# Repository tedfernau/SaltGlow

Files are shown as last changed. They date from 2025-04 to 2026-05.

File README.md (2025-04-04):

# SaltGlow

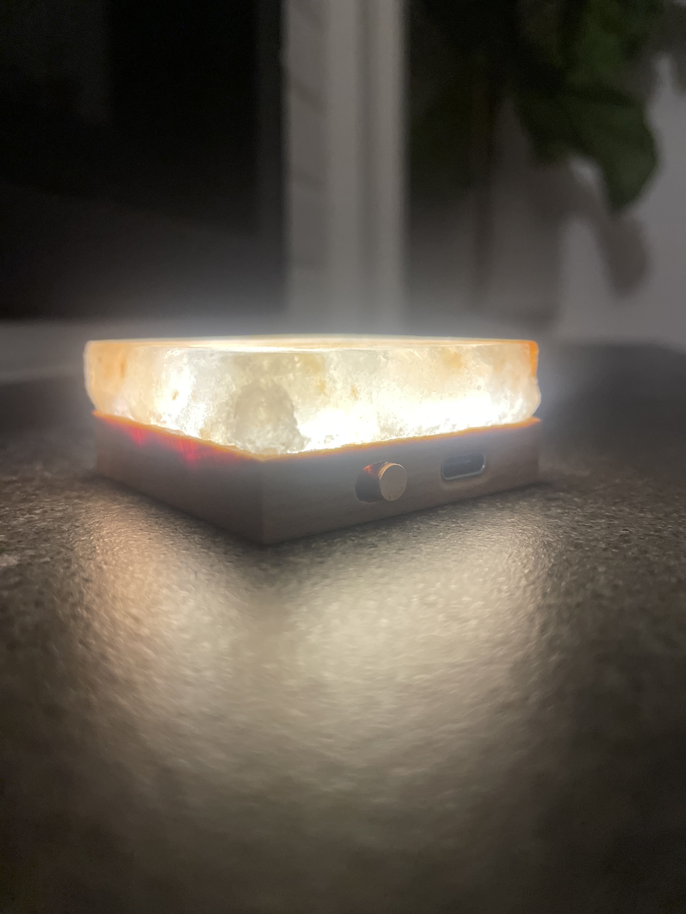
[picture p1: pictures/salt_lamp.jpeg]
SaltGlow


A portable saltlamp for camping, reading, or just setting the mood. 

Simple materials for modern living: Salt, Copper, Wood. 

Features: \
-USBC rechargable in less than 2 hours (100 minutes) (dumb charger only)\
-11 hour battery life - Max Brightness\
-about 5.5 days battery life - Low Brightness\
-3 Brightness Settings\
-Simple Materials\
-Each Lamp is Unique\
-Hand Assembled and Salt Selected\
-Designed in USA\
-Small Batch\

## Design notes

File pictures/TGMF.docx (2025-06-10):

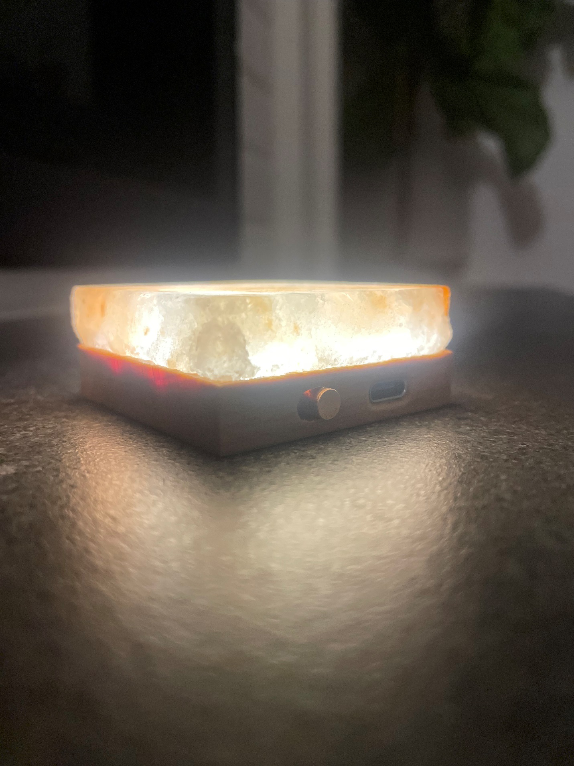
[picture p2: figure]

TGMF

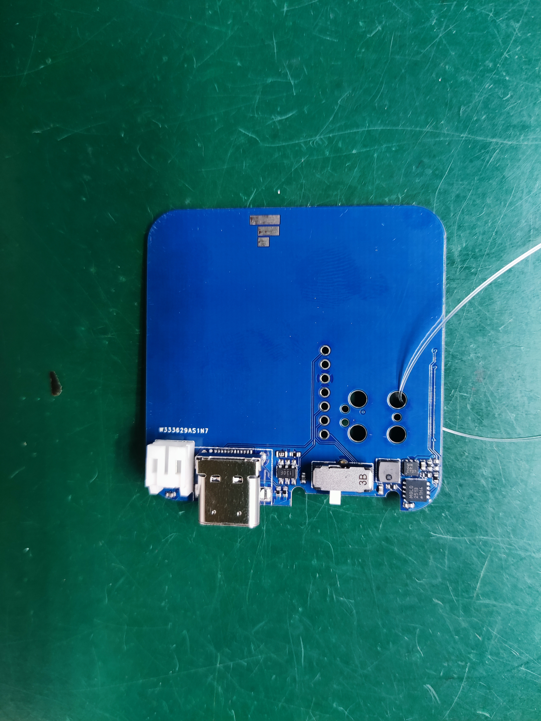
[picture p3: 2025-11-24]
pictures/T-1N8W333629A1.jpg

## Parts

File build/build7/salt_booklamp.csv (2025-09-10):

# | Qty | Reference | Manufacturer Part Number | Value
1 | 1 | BATT1 | S2B-PH-K-S | S2B-PH-K-S
2 | 5 | C1,C2,C3,C4,C5 | EMK105BJ105KV-F | 1uF
3 | 1 | J1 | USB-C31-S-RA-CS1E-BK-T/R | USB-C31-S-RA-CS1E-BK-T/R
4 | 1 | L1 | VLS3012CX-220M-1 | 22uH
5 | 3 | LED1,LED2,LED3 | SMS1105UWDW | SMS1105UWDW
6 | 4 | R1,R3,R4,R5 | RC0402JR-0710KL | 10k0
7 | 1 | R2 | CRCW04026R80FKED | 6r8
8 | 1 | R6 | CR0603-FX-1201ELF | 1k2
9 | 2 | R9,R10 | RC0402JR-071K2L | 5k1
10 | 1 | S1 | CL-SB-12C-12 | CL-SB-12C-12
11 | 1 | U1 | PIC16F15213T-I/MF | PIC16F15213T-I/MF
12 | 1 | U2 | BQ21040DBVR | BQ21040DBVR
13 | 1 | U3 | TPS61158DRVR | TPS61158DRVR

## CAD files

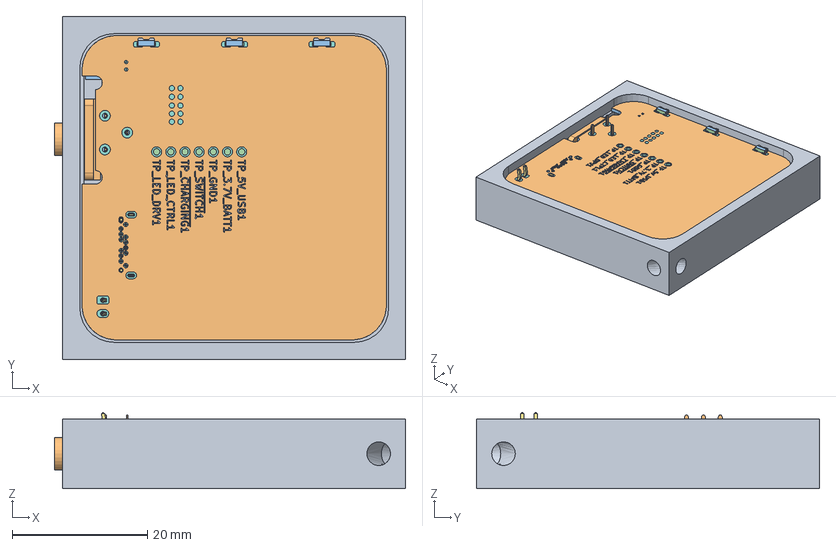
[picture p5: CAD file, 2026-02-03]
mechanical/salt_booklamp.FCStd
52.1 x 50.8 x 11.3 mm
Wood Enclosure - CNC Beech - water-poly finish
Switch Cover - CNC Copper
switch retainer plate
Battery - 524334
C_0402_1005Metric
R_0402_1005Metric
R_0402_1005Metric020
C_0402_1005Metric010
2Side setting_s001
12C-11_c001
BODY-SON001
BODY-SOT001
LEAD-SOT017
LEAD-SOT018
LEAD-SOT019
LEAD-SOT020
LEAD-SOT021
LEAD-SOT022
R_0402_1005Metric021
DFN-8-1EP_3x3mm_P0.65mm_EP1.55x2.4mm
R_0402_1005Metric022
vls3012cx-001
C_0402_1005Metric011
JST_PH_S2B-PH-K_1x02_P2.00mm_Horizontal
R_0402_1005Metric023
R_0402_1005Metric024
C_0402_1005Metric012
R_0402_1005Metric025
C_0402_1005Metric013
R_0402_1005Metric026
R_0402_1005Metric027
usb-c31-s-ra-cs1e-bk-t-r-model001
salt_booklamp_copper001
salt_booklamp_silkscreen001
salt_booklamp_soldermask001
salt_booklamp_PCB001

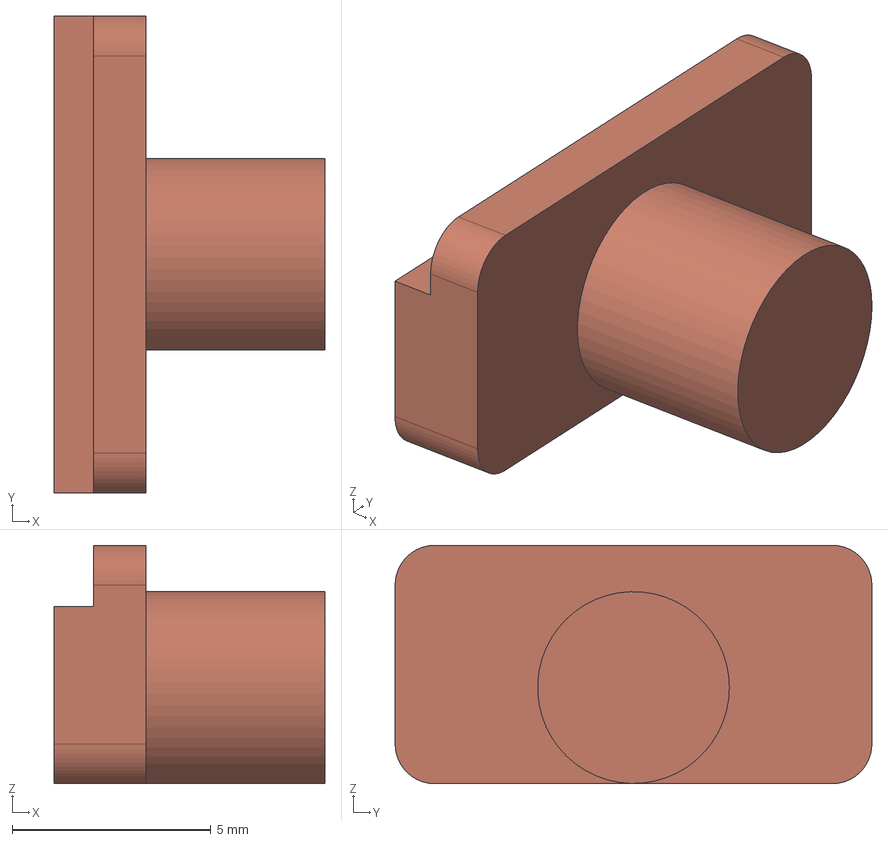
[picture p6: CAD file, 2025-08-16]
build/build7/copper_switch_cover_CNC.step
6.82 x 12.0 x 6.00 mm

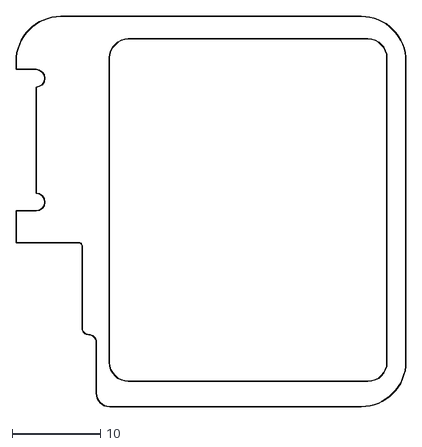
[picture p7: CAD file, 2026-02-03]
mechanical/salt_booklamp-switch retainer plateSketch045.dxf
44.1 x 44.1

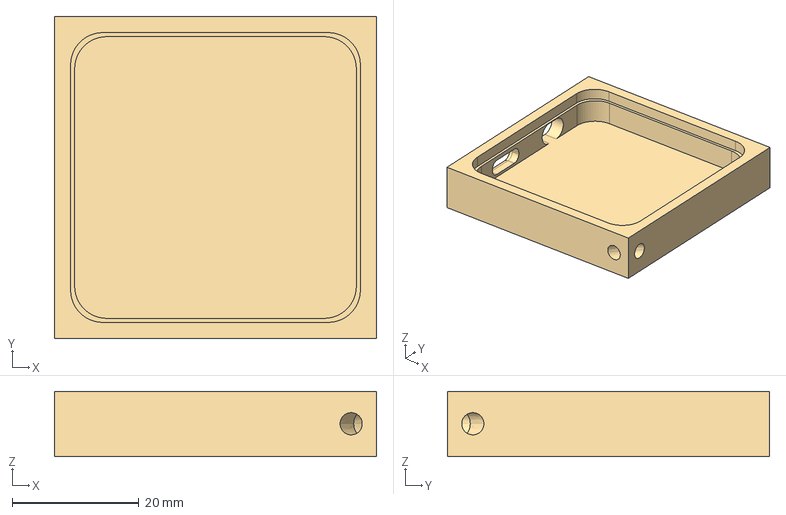
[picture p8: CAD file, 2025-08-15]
build/build7/wood_enclosure_CNC.step
50.8 x 50.8 x 10.3 mm

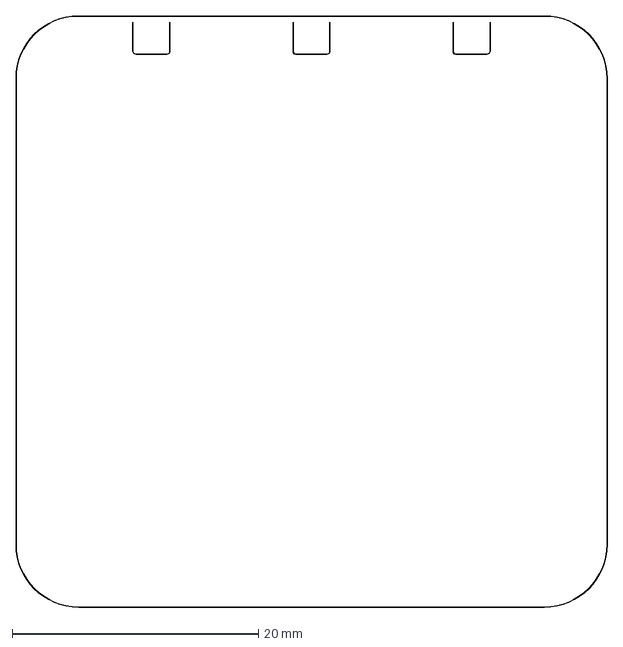
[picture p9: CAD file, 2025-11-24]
mechanical/mirror film outline.dxf
48.0 x 48.0 mm

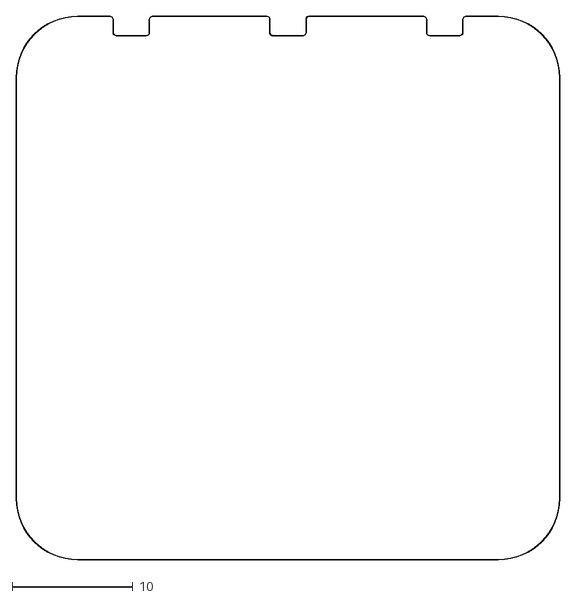
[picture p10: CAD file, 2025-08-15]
build/build7/salt_booklamp-mirror film outline.dxf
45.1 x 45.1

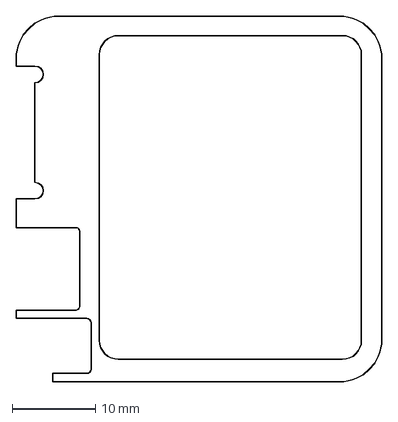
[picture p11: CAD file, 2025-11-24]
mechanical/salt_booklamp-switch retainer plate.dxf
44.0 x 44.0 mm

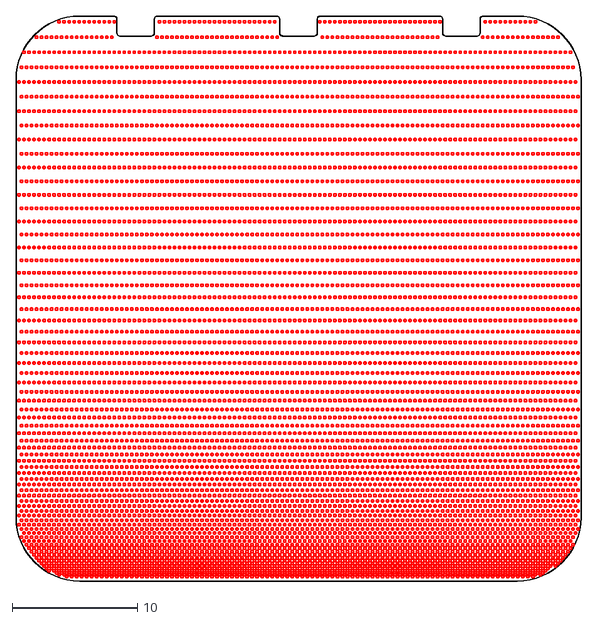
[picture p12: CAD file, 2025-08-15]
build/build7/salt_booklamp-LGP drawing for DXF.dxf
45.1 x 45.1

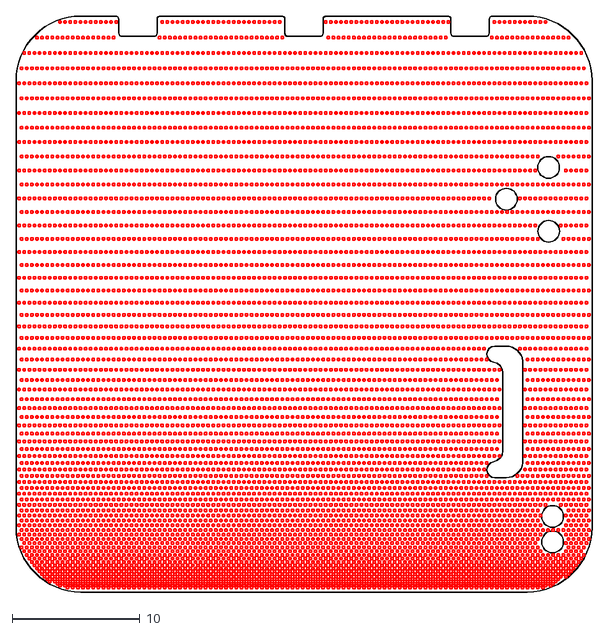
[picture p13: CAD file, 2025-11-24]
mechanical/lgp.dxf
45.1 x 45.1

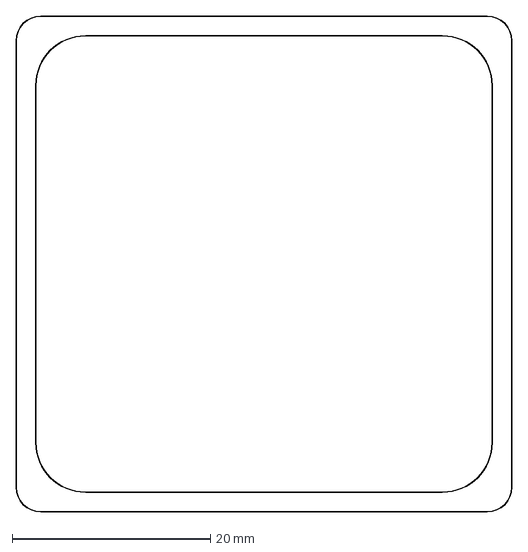
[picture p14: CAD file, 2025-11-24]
mechanical/adhesive film.dxf
50.0 x 50.0 mm

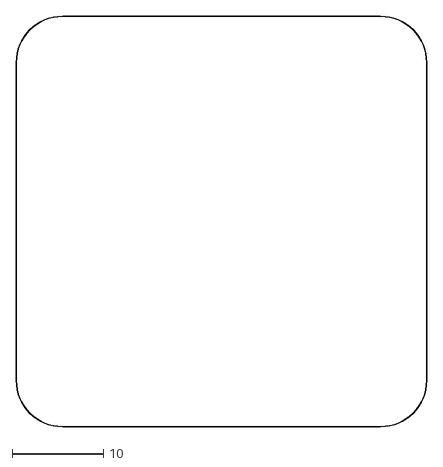
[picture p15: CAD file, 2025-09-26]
mechanical/diffuser outline.dxf
45.1 x 45.1

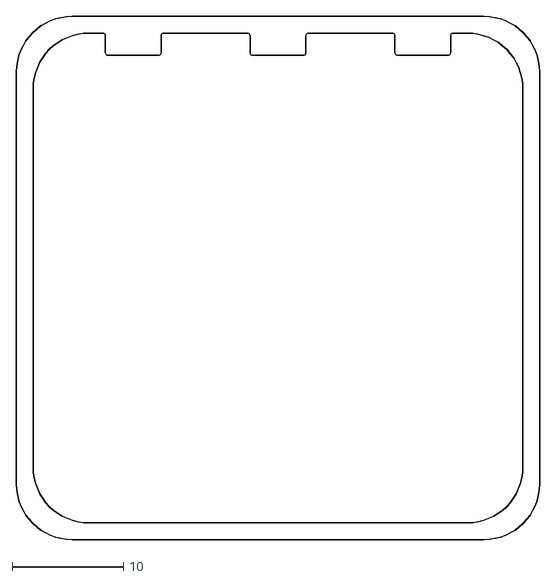
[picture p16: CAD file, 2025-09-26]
mechanical/blackout film outline.dxf
47.0 x 47.0

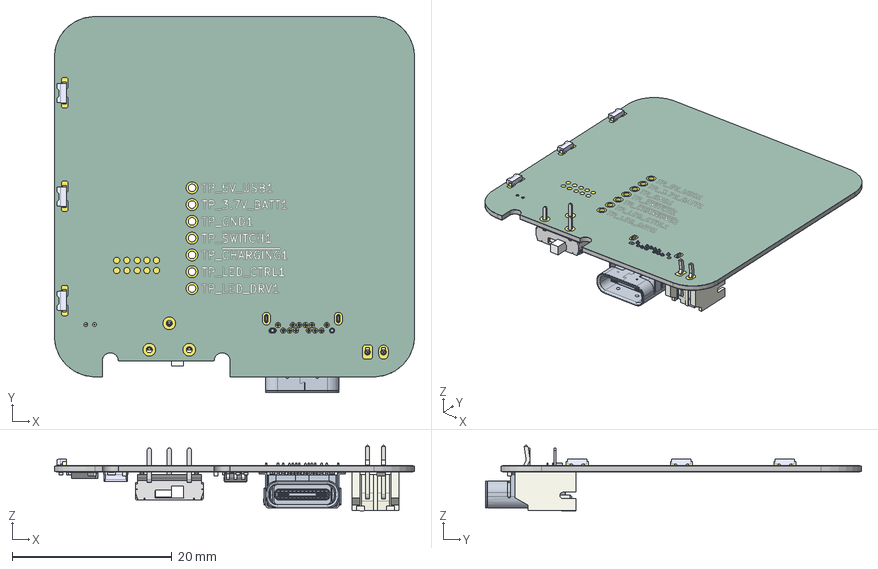
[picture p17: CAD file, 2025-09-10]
mechanical/salt_booklamp_pca.step
45.1 x 47.0 x 8.25 mm
C_0402_1005Metric x 5
R_0402_1005Metric x 9
2Side setting_s
12C-11_c
BODY-SON
PIN1-ID
BODY-SOT
LEAD-SOT x 6
DFN-8-1EP_3x3mm_P0.65mm_EP1.55x2.4mm
vls3012cx-1
JST_PH_S2B-PH-K_1x02_P2.00mm_Horizontal
usb-c31-s-ra-cs1e-bk-t-r-model
salt_booklamp_copper
salt_booklamp_silkscreen
salt_booklamp_soldermask
salt_booklamp_PCB

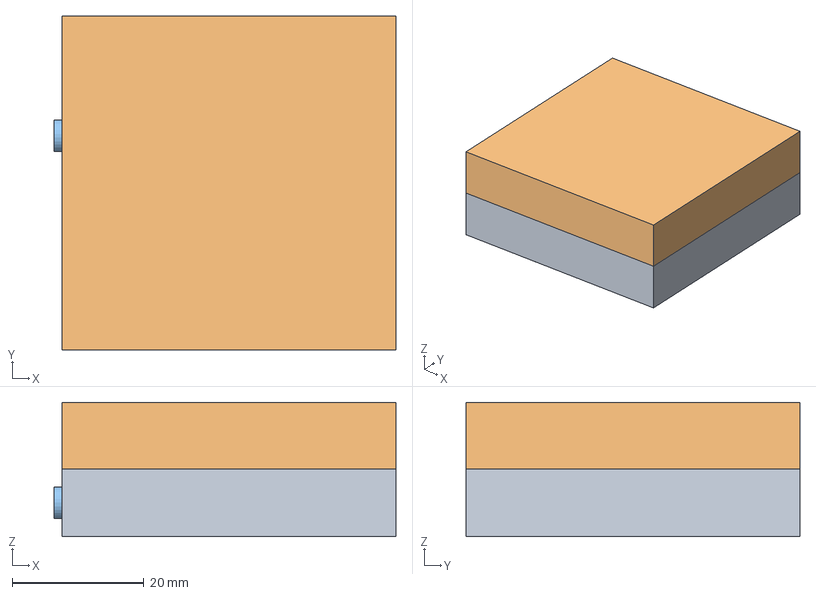
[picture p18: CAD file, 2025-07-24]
mechanical/salt_booklamp-7F34Q94.FCStd
52.0 x 50.8 x 20.4 mm
Wood Enclosure - CNC Beech - water-poly finish
Salt Block
Switch Cover - CNC Copper
Light Guide Plate - Acrylic - 1mm
cap_0603
Pad001_(Mirror_#1)
cap_0604
2Side setting_s
12C-11_c
BODY-SON
BODY-SOT
LEAD-SOT
LEAD-SOT001
LEAD-SOT002
LEAD-SOT003
LEAD-SOT004
LEAD-SOT005
Pad001_(Mirror_#1)001
SOIC8_SN_MCH
Pad001_(Mirror_#1)002
vls3012cx-1
cap_0605
Pad001_(Mirror_#1)003
Pad001_(Mirror_#1)004
cap_0606
Pad001_(Mirror_#1)005
cap_0607
Pad001_(Mirror_#1)006
usb-c31-s-ra-cs1e-bk-t-r-model
salt_booklamp_copper
salt_booklamp_silkscreen
salt_booklamp_soldermask
salt_booklamp_PCB
switch retainer plate
Battery - 524334

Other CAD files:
build/build7/retainer_plate.step
mechanical/salt_booklamp-Wood Enclosure.stl
build/build7/retainer_plate.dxf

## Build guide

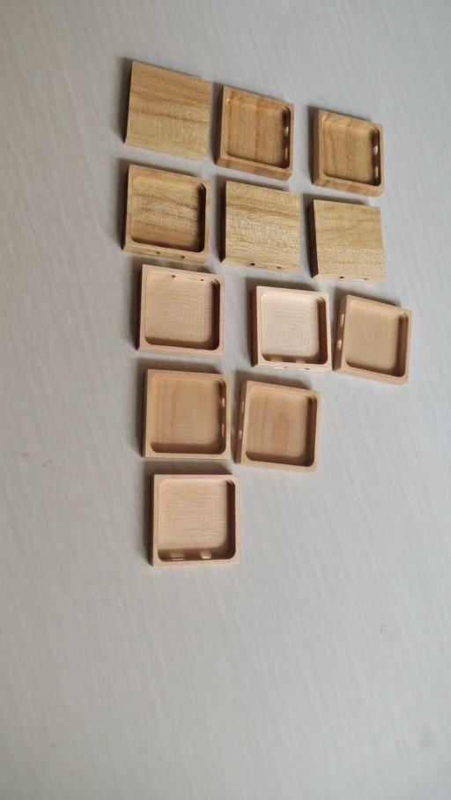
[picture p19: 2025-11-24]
build/build7/wood.jpg

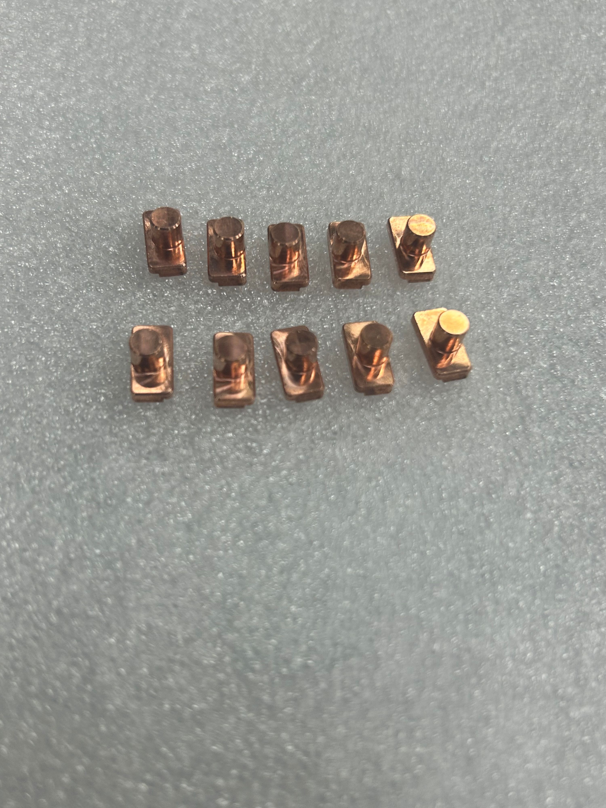
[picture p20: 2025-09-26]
build/build7/copper.jpg

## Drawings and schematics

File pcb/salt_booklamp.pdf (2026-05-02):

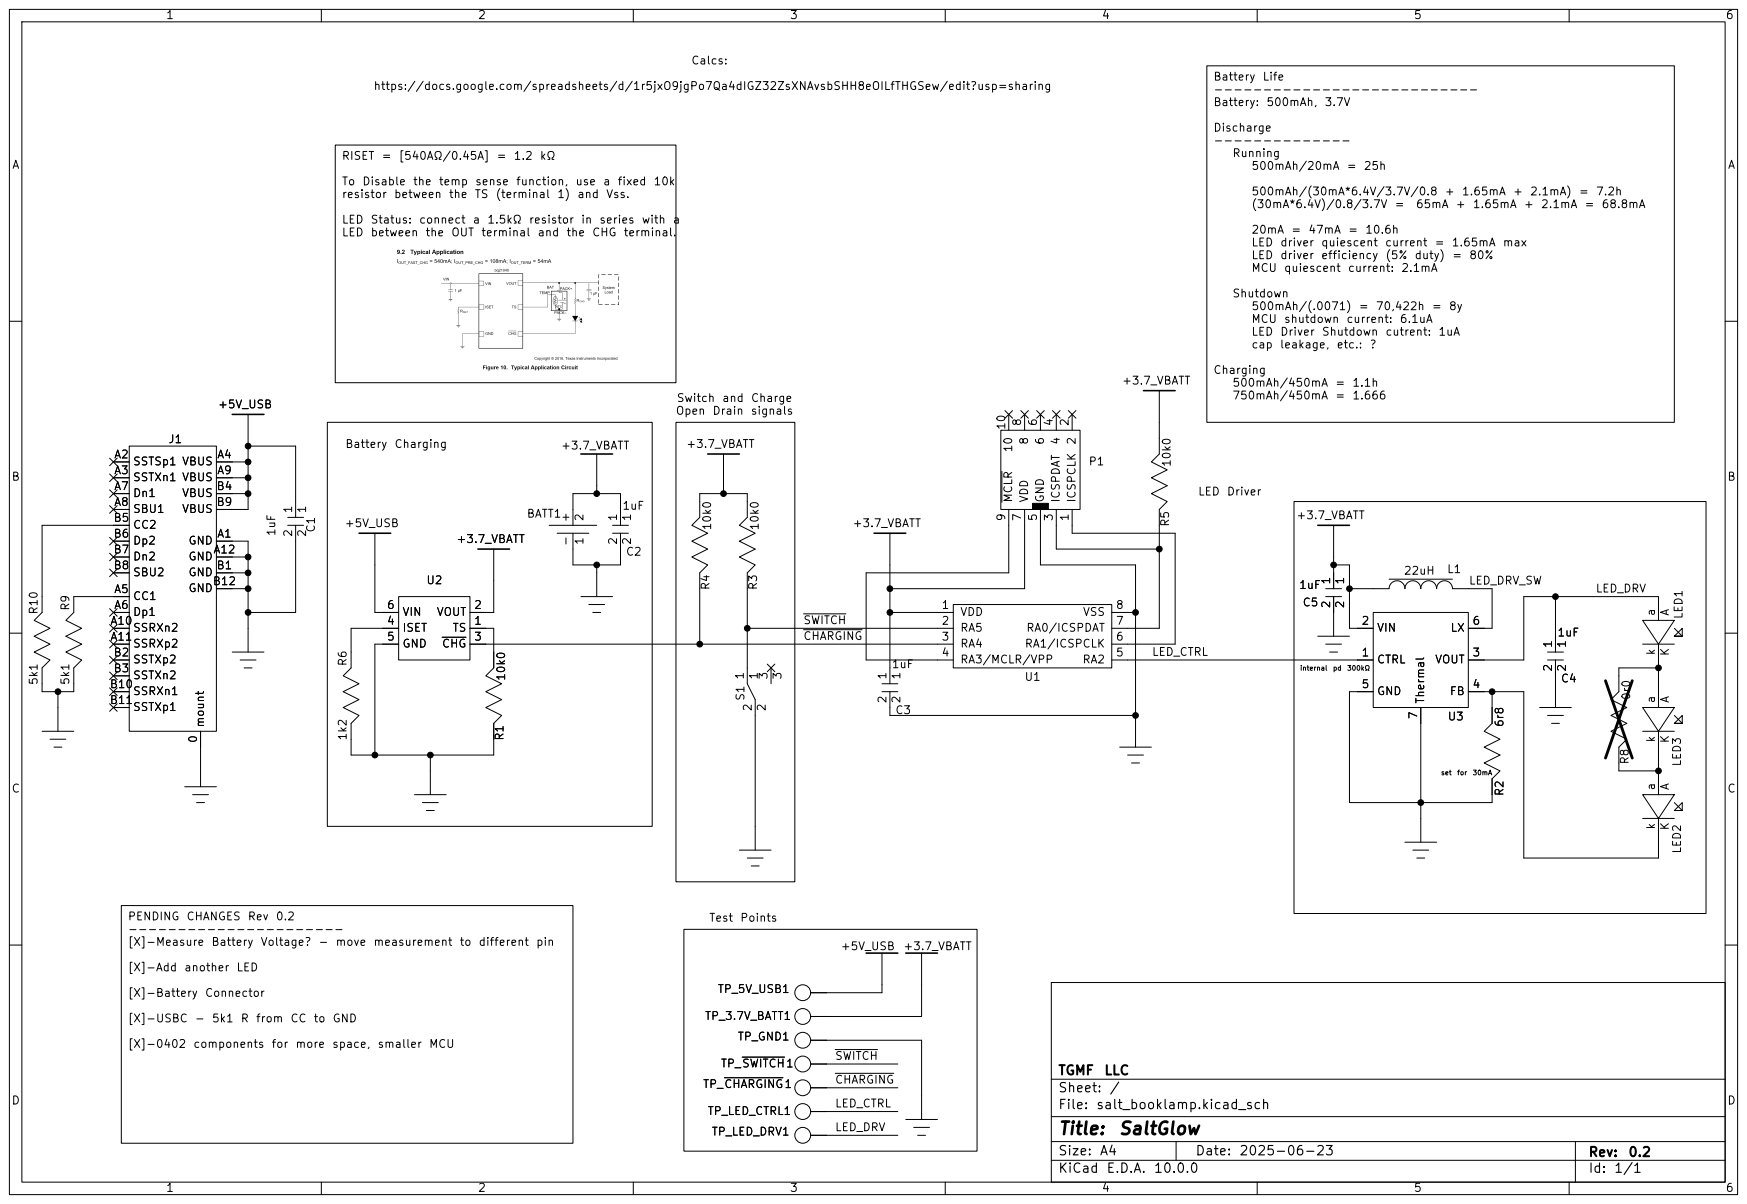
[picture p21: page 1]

https://docs.google.com/spreadsheets/d/1r5jxO9jgPo7Qa4dIGZ32ZsXNAvsbSHH8eOILfTHGSew/edit?usp=sharing

To Disable the temp sense function, use a fixed 10k
resistor between the TS (terminal 1) and Vss. LED Status: connect a 1.5kΩ resistor in series with a

LED driver quiescent current = 1.65mA max
LED driver efficiency (5% duty) = 80%
MCU quiescent current: 2.1mA Shutdown 500mAh/(.0071) = 70,422h = 8y

MCU shutdown current: 6.1uA
LED Driver Shutdown cutrent: 1uA

cap leakage, etc.: ? Charging

LED Driver Battery Charging

[X]-Measure Battery Voltage? - move measurement to different pin

[X]-Battery Connector [X]-USBC - 5k1 R from CC to GND

[X]-0402 components for more space, smaller MCU

Size: A4 | Rev: 0.2

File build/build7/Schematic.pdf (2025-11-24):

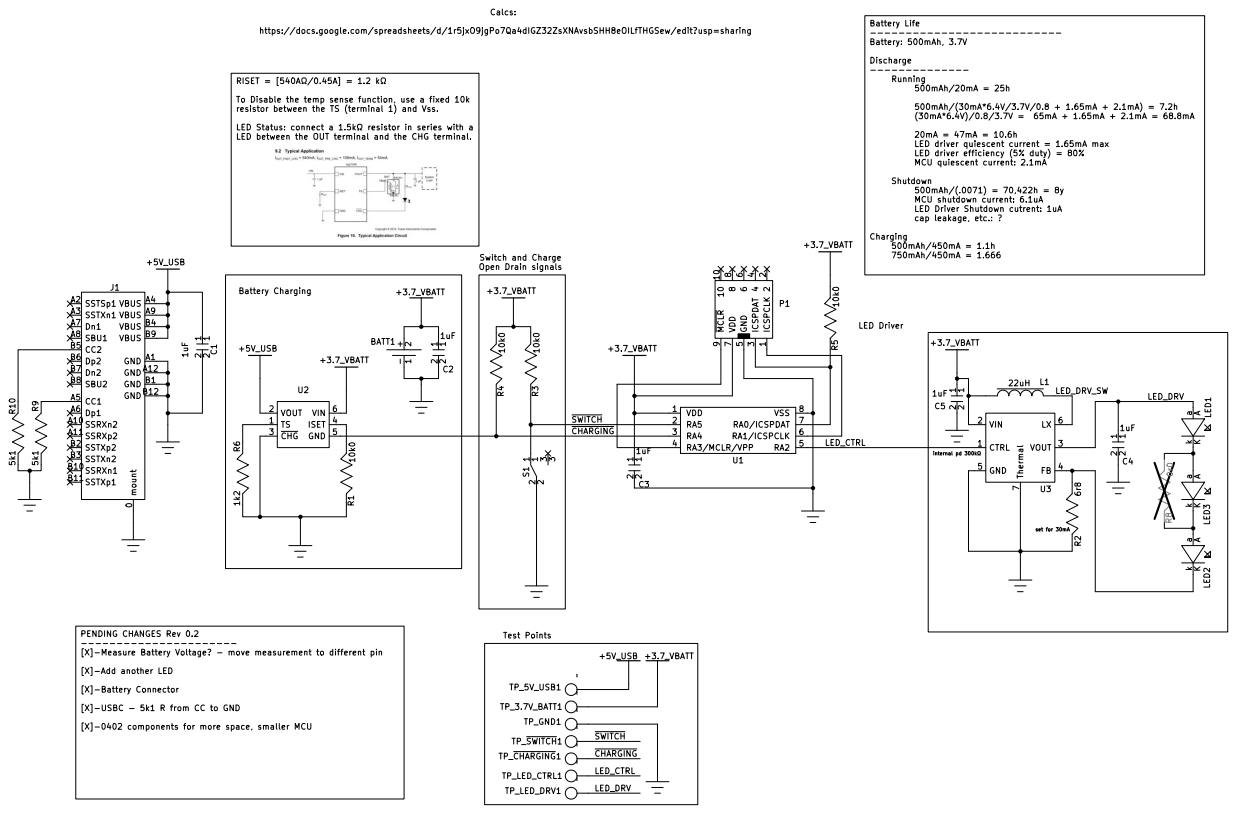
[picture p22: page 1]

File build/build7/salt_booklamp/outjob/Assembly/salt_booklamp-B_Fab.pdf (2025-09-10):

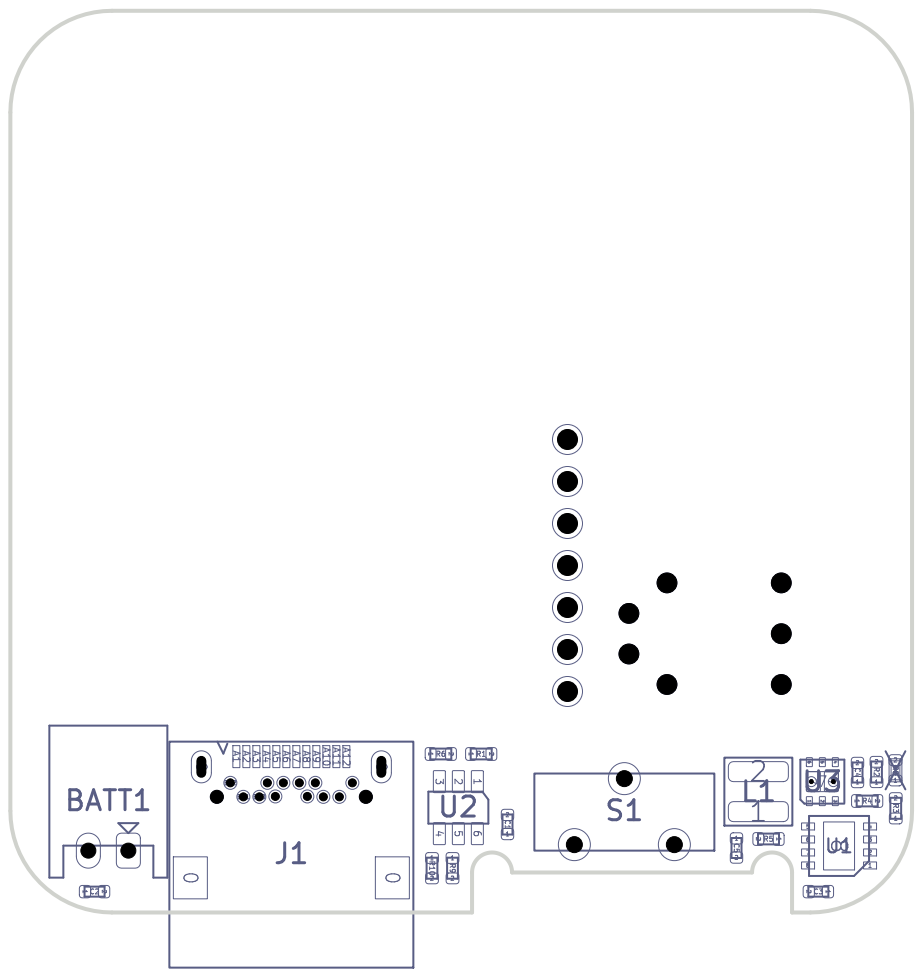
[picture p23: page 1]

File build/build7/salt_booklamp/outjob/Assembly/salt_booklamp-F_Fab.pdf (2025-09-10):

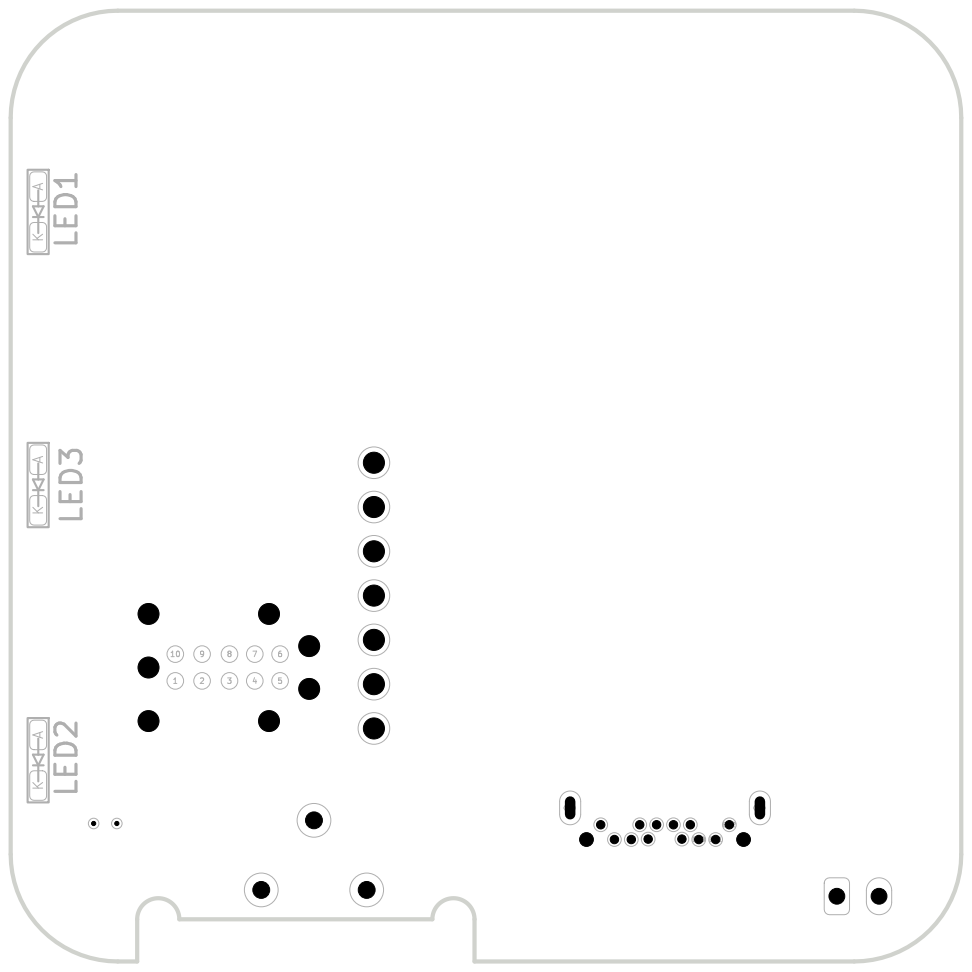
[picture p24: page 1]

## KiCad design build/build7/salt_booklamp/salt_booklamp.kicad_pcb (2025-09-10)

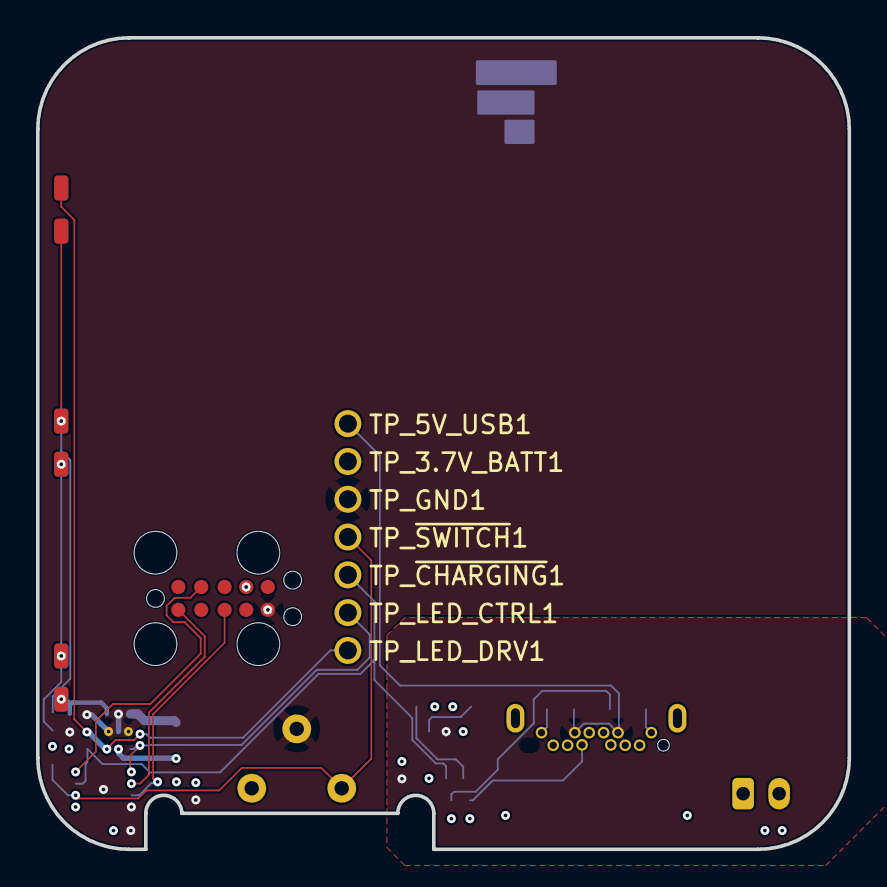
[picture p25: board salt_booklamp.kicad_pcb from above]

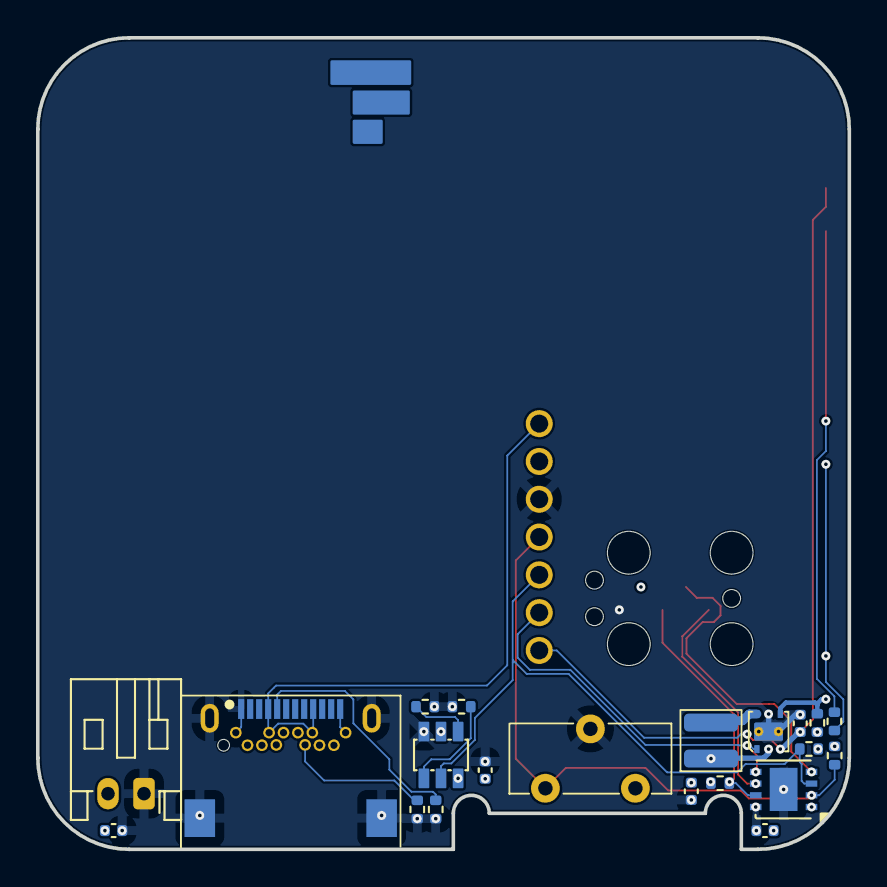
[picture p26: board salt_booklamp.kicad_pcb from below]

Board: 4 copper layers, 45.1 x 45.1 mm, 32 parts (21 on the bottom side), 18 nets.

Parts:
BATT1: S2B-PH-K-S; JST_PH_S2B-PH-K_1x02_P2.00mm_Horizontal
C1, C2, C3, C4, C5: 1uF; C_0402_1005Metric
J1: USB-C31-S-RA-CS1E-BK-T/R; USB-C31-S-RA-CS1E-BK
L1: 22uH; ind_VLS3012CX
LED1, LED2, LED3: SMS1105UWDW; LED_SMS1105UWDW
P1: PIC-TC2050-IDC; TC2050-IDC
R1, R3, R4, R5: 10k0; R_0402_1005Metric
R2: 6r8; R_0402_1005Metric
R6: 1k2; R_0402_1005Metric
R8: 0r0; R_0402_1005Metric
R9, R10: 5k1; R_0402_1005Metric
S1: CL-SB-12C-12; CL-SB-12C-11
TP_3.7V_BATT1, TP_5V_USB1: 1-pin header
TP_GND1: 1-pin header
TP_LED_CTRL1: 1-pin header
TP_LED_DRV1: 1-pin header
TP_~{CHARGING}1: 1-pin header
TP_~{SWITCH}1: 1-pin header
U1: PIC16F15213T-I/MF; DFN-8-1EP_3x3mm_P0.65mm_EP1.55x2.4mm
U2: BQ21040DBVR
U3: TPS61158DRVR; 6-WDFN - TPS61158DRVR

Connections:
+3.7_VBATT: BATT1.2 (+), C2.1, C3.1, C5.1, L1.1, P1.7 (VDD), R3.2, R4.2, R5.2, TP_3.7V_BATT1.1, U1.1 (VDD), U2.6 (VIN), U3.2 (VIN)
+5V_USB: C1.1, J1.A4 (VBUS), J1.A9 (VBUS), J1.B4 (VBUS), J1.B9 (VBUS), TP_5V_USB1.1, U2.2 (VOUT)
/LED_CTRL: TP_LED_CTRL1.1, U1.5 (RA2), U3.1 (CTRL)
/LED_DRV: C4.1, LED1.A (a), TP_LED_DRV1.1, U3.3 (VOUT)
/LED_DRV_SW: L1.2, U3.6 (LX)
/~CHARGING: R4.1, TP_~{CHARGING}1.1, U1.3 (RA4), U2.5 (GND)
/~SWITCH: R3.1, S1.1, TP_~{SWITCH}1.1, U1.2 (RA5)
GND: BATT1.1 (-), C1.2, C2.2, C3.2, C4.2, C5.2, J1.0 (mount), J1.A1 (GND), J1.A12 (GND), J1.B1 (GND), J1.B12 (GND), P1.5 (GND), R1.1, R2.1, R6.2, R9.2, R10.2, S1.2, TP_GND1.1, U1.8 (VSS), U2.3 (~CHG), U3.5 (GND), U3.7 (Thermal)
unnamed: J1.A5 (CC1), R9.1
unnamed: J1.B5 (CC2), R10.1
unnamed: LED1.K (k), LED3.A (a), R8.2
unnamed: LED2.A (a), LED3.K (k), R8.1
unnamed: LED2.K (k), R2.2, U3.4 (FB)
unnamed: P1.1 (ICSPCLK), U1.6 (RA1/ICSPCLK)
unnamed: P1.3 (ICSPDAT), R5.1, U1.7 (RA0/ICSPDAT)
unnamed: P1.9 (~MCLR), U1.4 (RA3/MCLR/VPP)
unnamed: R1.2, U2.4 (ISET)
unnamed: R6.1, U2.1 (TS)

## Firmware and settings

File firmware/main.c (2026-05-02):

 /*
 * MAIN Generated Driver File
 * 
 * @file main.c
 * 
 * @defgroup main MAIN
 * 
 * @brief This is the generated driver implementation file for the MAIN driver.
 *
 * @version MAIN Driver Version 1.0.2
 *
 * @version Package Version: 3.1.2
*/

/*
© [2026] Microchip Technology Inc. and its subsidiaries.

    Subject to your compliance with these terms, you may use Microchip 
    software and any derivatives exclusively with Microchip products. 
    You are responsible for complying with 3rd party license terms  
    applicable to your use of 3rd party software (including open source  
    software) that may accompany Microchip software. SOFTWARE IS ?AS IS.? 
    NO WARRANTIES, WHETHER EXPRESS, IMPLIED OR STATUTORY, APPLY TO THIS 
    SOFTWARE, INCLUDING ANY IMPLIED WARRANTIES OF NON-INFRINGEMENT,  
    MERCHANTABILITY, OR FITNESS FOR A PARTICULAR PURPOSE. IN NO EVENT 
    WILL MICROCHIP BE LIABLE FOR ANY INDIRECT, SPECIAL, PUNITIVE, 
    INCIDENTAL OR CONSEQUENTIAL LOSS, DAMAGE, COST OR EXPENSE OF ANY 
    KIND WHATSOEVER RELATED TO THE SOFTWARE, HOWEVER CAUSED, EVEN IF 
    MICROCHIP HAS BEEN ADVISED OF THE POSSIBILITY OR THE DAMAGES ARE 
    FORESEEABLE. TO THE FULLEST EXTENT ALLOWED BY LAW, MICROCHIP?S 
    TOTAL LIABILITY ON ALL CLAIMS RELATED TO THE SOFTWARE WILL NOT 
    EXCEED AMOUNT OF FEES, IF ANY, YOU PAID DIRECTLY TO MICROCHIP FOR 
    THIS SOFTWARE.
*/
#include "mcc_generated_files/system/system.h"

// enum brightness {
    // LOW_BRIGHTNESS, 
    // MED_BRIGHTNESS, 
    // HIGH_BRIGHTNESS
// };

    
inline void write_brightness_start()
{   
    
    LED_CTRL_SetLow();
    __delay_us(3500); //restart  3.5 ms     

    LED_CTRL_SetHigh();
    __delay_us(100); //easyscale detect delay 100us
    LED_CTRL_SetLow();
    __delay_us(450); //easyscale detect time 450us min

    
    

    // write address
    LED_CTRL_SetHigh();
    __delay_us(4); //start time min 3.5us

    LED_CTRL_SetLow(); //2 X high
    __delay_us(8);
     LED_CTRL_SetHigh(); //3.5-300us
    __delay_us(4);

    LED_CTRL_SetLow(); //3.5-300us
    __delay_us(4); 
     LED_CTRL_SetHigh(); //2 X low
    __delay_us(8);

    LED_CTRL_SetLow(); //2 X high
    __delay_us(8);
     LED_CTRL_SetHigh(); //3.5-300us
    __delay_us(4);

    LED_CTRL_SetLow(); //3.5-300us
    __delay_us(4); 
     LED_CTRL_SetHigh(); //2 X low
    __delay_us(8);

    LED_CTRL_SetLow(); //3.5-300us
    __delay_us(4); 
     LED_CTRL_SetHigh(); //2 X low
    __delay_us(8);

    LED_CTRL_SetLow(); //2 X high
    __delay_us(8);
     LED_CTRL_SetHigh(); //3.5-300us
    __delay_us(4);

    LED_CTRL_SetLow(); //2 X high
    __delay_us(8);
     LED_CTRL_SetHigh(); //3.5-300us
    __delay_us(4);

   LED_CTRL_SetLow(); //2 X high
    __delay_us(8);
     LED_CTRL_SetHigh(); //3.5-300us
    __delay_us(4);
    
    LED_CTRL_SetLow(); //EOS 3.5-600us
    __delay_us(4);

}


inline void write_brightness(uint8_t brightness)
{
	write_brightness_start();
    
        //write brightness

    LED_CTRL_SetHigh();
    __delay_us(4); //start time min 3.5us

    LED_CTRL_SetLow(); //2 X high
    __delay_us(20);
     LED_CTRL_SetHigh(); //3.5-300us
    __delay_us(4);

    LED_CTRL_SetLow(); //2 X high
    __delay_us(20);
     LED_CTRL_SetHigh(); //3.5-300us
    __delay_us(4);

    LED_CTRL_SetLow(); //2 X high
    __delay_us(20);
     LED_CTRL_SetHigh(); //3.5-300us
    __delay_us(4);
	
	for( int i = 4; i >= 0; i--) {
	
		if (((brightness & (1 << i )) >> i) == 0 ) {
        
        //write 0
        LED_CTRL_SetLow(); //2 X high
        __delay_us(20);
         LED_CTRL_SetHigh(); //3.5-300us
        __delay_us(4);
		
		} else {
			
        //write 1
        LED_CTRL_SetLow(); //3.5-300us
        __delay_us(4); 
         LED_CTRL_SetHigh(); //2 X low
        __delay_us(20);
		
		}
                

    }
    
    LED_CTRL_SetLow(); //EOS 3.5-600us
    __delay_us(4);
    
    LED_CTRL_SetHigh();//static high
}
   

/*
    Main application
*/

int main(void)
{
    SYSTEM_Initialize();
    // If using interrupts in PIC18 High/Low Priority Mode you need to enable the Global High and Low Interrupts 
    // If using interrupts in PIC Mid-Range Compatibility Mode you need to enable the Global and Peripheral Interrupts 
    // Use the following macros to: 

    // Enable the Global Interrupts 
    INTERRUPT_GlobalInterruptEnable(); 

    // Disable the Global Interrupts 
    //INTERRUPT_GlobalInterruptDisable(); 

    // Enable the Peripheral Interrupts 
    INTERRUPT_PeripheralInterruptEnable(); 

    // Disable the Peripheral Interrupts 
    //INTERRUPT_PeripheralInterruptDisable(); 

    uint8_t current_brightness = 1;
    uint8_t next_brightness = 1;
    bool previous_charging_status = 1;
	bool breathe_up = 1;
  
    
    
    
    while(1)
    {
       
        SLEEP();
        NOP();
            if (SWITCH_N_GetValue() == 0x1) {
                
                LED_CTRL_SetLow();
                
                __delay_ms(300);

                //while (SWITCH_N_GetValue() != 0x1) {
                if (SWITCH_N_GetValue() != 0x1) {
                    
					
                    //write_brightness(current_brightness);
                    
                    if (current_brightness == 31){
                        next_brightness = 1; 
                    }
                    else if(current_brightness ==16){
                        next_brightness = 31; 
                    }
                    else if(current_brightness ==1){
                        next_brightness = 16; 
                    }
                    current_brightness = next_brightness;
					

                    for(int i = 1; i <= current_brightness; i++){
                    write_brightness(i);
                    __delay_ms(10);
                    }
                    
					
//					if (current_brightness >= 31){
//                        breathe_up = 0; 
//                    }
//                    else if(current_brightness <= 0){
//                        breathe_up = 1; 
//                    }
//					
//                    if (breathe_up == 0){
//                        current_brightness--; 
//                    }
//                    else if(breathe_up == 1){
//                        current_brightness++;
//                    }
//                    write_brightness(current_brightness);
//                    
                    
//                    write_brightness(1);
//                    
                    __delay_ms(50);
//                    LED_CTRL_SetLow();
//                    __delay_ms(500);
                    
                }
            
           } else {
                //LED_CTRL_SetHigh();
                for(int i = 1; i <= current_brightness; i++){
                write_brightness(i);
                __delay_ms(10);
                }
                    
                    // quick switch, change brightness
                    //write_brightness(current_brightness);
                    
                    //save new brightness
                }
                
        
            
        
        if (CHARGING_N_GetValue() == 0x1) { //not charging
            if (previous_charging_status  == 0) {//got unplugged
            previous_charging_status = 1;
            }
           } else { //charging
            
                if (previous_charging_status  == 1) { //got plugged
                    previous_charging_status = 0;

                    if (SWITCH_N_GetValue() == 0x1) {
                        write_brightness(current_brightness);
                        __delay_ms(500);
                        LED_CTRL_SetLow();
                    } else {
                        LED_CTRL_SetLow();
                        __delay_ms(500);
                        write_brightness(current_brightness);
                    }   
                }
           }
        //FLASH_Read(flash_address_t address);
        //FLASH_RowWrite(flash_address_t address, flash_data_t *dataBuffer);
            

            
    }    
}

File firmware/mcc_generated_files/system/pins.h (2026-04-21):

/**
 * Generated Pins header File
 * 
 * @file pins.h
 * 
 * @defgroup  pinsdriver Pins Driver
 * 
 * @brief This is generated driver header for pins. 
 *        This header file provides APIs for all pins selected in the GUI.
 *
 * @version Driver Version  3.0.0
*/

/*
© [2026] Microchip Technology Inc. and its subsidiaries.

    Subject to your compliance with these terms, you may use Microchip 
    software and any derivatives exclusively with Microchip products. 
    You are responsible for complying with 3rd party license terms  
    applicable to your use of 3rd party software (including open source  
    software) that may accompany Microchip software. SOFTWARE IS ?AS IS.? 
    NO WARRANTIES, WHETHER EXPRESS, IMPLIED OR STATUTORY, APPLY TO THIS 
    SOFTWARE, INCLUDING ANY IMPLIED WARRANTIES OF NON-INFRINGEMENT,  
    MERCHANTABILITY, OR FITNESS FOR A PARTICULAR PURPOSE. IN NO EVENT 
    WILL MICROCHIP BE LIABLE FOR ANY INDIRECT, SPECIAL, PUNITIVE, 
    INCIDENTAL OR CONSEQUENTIAL LOSS, DAMAGE, COST OR EXPENSE OF ANY 
    KIND WHATSOEVER RELATED TO THE SOFTWARE, HOWEVER CAUSED, EVEN IF 
    MICROCHIP HAS BEEN ADVISED OF THE POSSIBILITY OR THE DAMAGES ARE 
    FORESEEABLE. TO THE FULLEST EXTENT ALLOWED BY LAW, MICROCHIP?S 
    TOTAL LIABILITY ON ALL CLAIMS RELATED TO THE SOFTWARE WILL NOT 
    EXCEED AMOUNT OF FEES, IF ANY, YOU PAID DIRECTLY TO MICROCHIP FOR 
    THIS SOFTWARE.
*/

#ifndef PINS_H
#define PINS_H

#include <xc.h>

#define INPUT   1
#define OUTPUT  0

#define HIGH    1
#define LOW     0

#define ANALOG      1
#define DIGITAL     0

#define PULL_UP_ENABLED      1
#define PULL_UP_DISABLED     0

// get/set IO_RA2 aliases
#define LED_CTRL_TRIS                 TRISAbits.TRISA2
#define LED_CTRL_LAT                  LATAbits.LATA2
#define LED_CTRL_PORT                 PORTAbits.RA2
#define LED_CTRL_WPU                  WPUAbits.WPUA2
#define LED_CTRL_OD                   ODCONAbits.ODCA2
#define LED_CTRL_ANS                  ANSELAbits.ANSA2
#define LED_CTRL_SetHigh()            do { LATAbits.LATA2 = 1; } while(0)
#define LED_CTRL_SetLow()             do { LATAbits.LATA2 = 0; } while(0)
#define LED_CTRL_Toggle()             do { LATAbits.LATA2 = ~LATAbits.LATA2; } while(0)
#define LED_CTRL_GetValue()           PORTAbits.RA2
#define LED_CTRL_SetDigitalInput()    do { TRISAbits.TRISA2 = 1; } while(0)
#define LED_CTRL_SetDigitalOutput()   do { TRISAbits.TRISA2 = 0; } while(0)
#define LED_CTRL_SetPullup()          do { WPUAbits.WPUA2 = 1; } while(0)
#define LED_CTRL_ResetPullup()        do { WPUAbits.WPUA2 = 0; } while(0)
#define LED_CTRL_SetPushPull()        do { ODCONAbits.ODCA2 = 0; } while(0)
#define LED_CTRL_SetOpenDrain()       do { ODCONAbits.ODCA2 = 1; } while(0)
#define LED_CTRL_SetAnalogMode()      do { ANSELAbits.ANSA2 = 1; } while(0)
#define LED_CTRL_SetDigitalMode()     do { ANSELAbits.ANSA2 = 0; } while(0)
// get/set IO_RA4 aliases
#define CHARGING_N_TRIS                 TRISAbits.TRISA4
#define CHARGING_N_LAT                  LATAbits.LATA4
#define CHARGING_N_PORT                 PORTAbits.RA4
#define CHARGING_N_WPU                  WPUAbits.WPUA4
#define CHARGING_N_OD                   ODCONAbits.ODCA4
#define CHARGING_N_ANS                  ANSELAbits.ANSA4
#define CHARGING_N_SetHigh()            do { LATAbits.LATA4 = 1; } while(0)
#define CHARGING_N_SetLow()             do { LATAbits.LATA4 = 0; } while(0)
#define CHARGING_N_Toggle()             do { LATAbits.LATA4 = ~LATAbits.LATA4; } while(0)
#define CHARGING_N_GetValue()           PORTAbits.RA4
#define CHARGING_N_SetDigitalInput()    do { TRISAbits.TRISA4 = 1; } while(0)
#define CHARGING_N_SetDigitalOutput()   do { TRISAbits.TRISA4 = 0; } while(0)
#define CHARGING_N_SetPullup()          do { WPUAbits.WPUA4 = 1; } while(0)
#define CHARGING_N_ResetPullup()        do { WPUAbits.WPUA4 = 0; } while(0)
#define CHARGING_N_SetPushPull()        do { ODCONAbits.ODCA4 = 0; } while(0)
#define CHARGING_N_SetOpenDrain()       do { ODCONAbits.ODCA4 = 1; } while(0)
#define CHARGING_N_SetAnalogMode()      do { ANSELAbits.ANSA4 = 1; } while(0)
#define CHARGING_N_SetDigitalMode()     do { ANSELAbits.ANSA4 = 0; } while(0)
#define RA4_SetInterruptHandler  CHARGING_N_SetInterruptHandler
// get/set IO_RA5 aliases
#define SWITCH_N_TRIS                 TRISAbits.TRISA5
#define SWITCH_N_LAT                  LATAbits.LATA5
#define SWITCH_N_PORT                 PORTAbits.RA5
#define SWITCH_N_WPU                  WPUAbits.WPUA5
#define SWITCH_N_OD                   ODCONAbits.ODCA5
#define SWITCH_N_ANS                  ANSELAbits.ANSA5
#define SWITCH_N_SetHigh()            do { LATAbits.LATA5 = 1; } while(0)
#define SWITCH_N_SetLow()             do { LATAbits.LATA5 = 0; } while(0)
#define SWITCH_N_Toggle()             do { LATAbits.LATA5 = ~LATAbits.LATA5; } while(0)
#define SWITCH_N_GetValue()           PORTAbits.RA5
#define SWITCH_N_SetDigitalInput()    do { TRISAbits.TRISA5 = 1; } while(0)
#define SWITCH_N_SetDigitalOutput()   do { TRISAbits.TRISA5 = 0; } while(0)
#define SWITCH_N_SetPullup()          do { WPUAbits.WPUA5 = 1; } while(0)
#define SWITCH_N_ResetPullup()        do { WPUAbits.WPUA5 = 0; } while(0)
#define SWITCH_N_SetPushPull()        do { ODCONAbits.ODCA5 = 0; } while(0)
#define SWITCH_N_SetOpenDrain()       do { ODCONAbits.ODCA5 = 1; } while(0)
#define SWITCH_N_SetAnalogMode()      do { ANSELAbits.ANSA5 = 1; } while(0)
#define SWITCH_N_SetDigitalMode()     do { ANSELAbits.ANSA5 = 0; } while(0)
#define RA5_SetInterruptHandler  SWITCH_N_SetInterruptHandler
/**
 * @ingroup  pinsdriver
 * @brief GPIO and peripheral I/O initialization
 * @param none
 * @return none
 */
void PIN_MANAGER_Initialize (void);

/**
 * @ingroup  pinsdriver
 * @brief Interrupt on Change Handling routine
 * @param none
 * @return none
 */
void PIN_MANAGER_IOC(void);

/**
 * @ingroup  pinsdriver
 * @brief Interrupt on Change Handler for the CHARGING_N pin functionality
 * @param none
 * @return none
 */
void CHARGING_N_ISR(void);

/**
 * @ingroup  pinsdriver
 * @brief Interrupt Handler Setter for CHARGING_N pin interrupt-on-change functionality.
 *        Allows selecting an interrupt handler for CHARGING_N at application runtime.
 * @pre Pins intializer called
 * @param InterruptHandler function pointer.
 * @return none
 */
void CHARGING_N_SetInterruptHandler(void (* InterruptHandler)(void));

/**
 * @ingroup  pinsdriver
 * @brief Dynamic Interrupt Handler for CHARGING_N pin.
 *        This is a dynamic interrupt handler to be used together with the CHARGING_N_SetInterruptHandler() method.
 *        This handler is called every time the CHARGING_N ISR is executed and allows any function to be registered at runtime.
 * @pre Pins intializer called
 * @param none
 * @return none
 */
extern void (*CHARGING_N_InterruptHandler)(void);
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

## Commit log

2025-04-04 Add mechanical files
    [lgp.dxf, mirror film outline.dxf]
2025-04-04 uploading project files
    [lgp.dxf, mirror film outline.dxf, salt_booklamp.kicad_pcb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]
2025-06-10 start creating an assembly
    [salt_booklamp.FCStd, salt_booklamp.kicad_sch, wood_enclosure_CNC.step]
2025-06-23 prepare for Rev 0.2 schematic changes
    [salt_booklamp.FCStd, salt_booklamp.kicad_sch]
2025-06-25 Add CC resistors to schematic for USB compliant smart chargers
    [salt_booklamp.kicad_sch]
2025-06-26 Changed 0603 parts to 0402, assigned 0402 uF cap MPN, still need to assign 0402 Resistor MPNs
    [salt_booklamp.kicad_pcb, salt_booklamp.kicad_sch]
2025-07-02 Changed MCU to smaller DFN package, add Connector footprint to PCB (very big), add shield pins to USB footprint to remove warning
    [salt_booklamp.kicad_pcb, salt_booklamp.kicad_sch]
2025-07-03 Moved battery voltage measurement to a different programming pin
    [salt_booklamp.kicad_sch]
2025-07-07 Start placement - new LED placement
    [salt_booklamp.kicad_pcb]
2025-07-08 Placement work
    [salt_booklamp.kicad_pcb, salt_booklamp.kicad_sch]
2025-07-16 changed placement of a couple resistors to achieve daily commit
    [salt_booklamp.kicad_pcb]
2025-07-17 Start updating light guide plate
    [salt_booklamp.FCStd]
2025-07-18 Work on placement for pcb .step transfer
    [salt_booklamp.FCStd, salt_booklamp_pca.step]
2025-07-22 light guide plate work
    [salt_booklamp.FCStd]
2025-07-25 remove old light guide plate sketches, rename light guide plate sketches
    [salt_booklamp.FCStd]
2025-07-25 make light guide plate 6.0 sketch
    [salt_booklamp.FCStd]
2025-07-28 placement work - may need smaller battery connector
    [salt_booklamp.kicad_pcb]
2025-07-29 initial placement for mechanical design -> redesign light guide for 3 LEDs, improve enclosure fit of PCB etc., evaluate battery connector
    [salt_booklamp.kicad_pcb, salt_booklamp_pca.step]
2025-07-29 redesign light guide for 3 LEDs
    [salt_booklamp.FCStd]
2025-07-30 Redo LGP model and cleanup
    [salt_booklamp.FCStd]
2025-08-12 adjust net classes and start routing
    [salt_booklamp.kicad_pcb, salt_booklamp.kicad_sch]
2025-08-13 add test point and clean up schematic
    [salt_booklamp.kicad_pcb, salt_booklamp.kicad_sch]
2025-08-14 made a CAM project to explore manufacturing process
    [salt_booklamp.FCStd]
2025-08-15 adjust placement of edge components in PCA, added lanyard hole in wood enclosure, updated light guide .dxf file, updated mirror film .dxf file, exported wood enclosure .step for quote, exported light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
    [copper_switch_cover_CNC.step, salt_booklamp-LGP drawing for DXF.dxf, salt_booklamp-mirror film outline.dxf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]
2025-08-16 Change size of internal routing on switch cover, add more meat to switch cover/switch interface, start work adjusting retainer plate
    [copper_switch_cover_CNC.step, salt_booklamp.FCStd]
2025-08-26 Routing work
    [salt_booklamp.FCStd, salt_booklamp.kicad_pcb, salt_booklamp.kicad_sch]
2025-09-10 ordered pca, wood, copper, batteries
    [BOM.csv, copper_switch_cover_CNC.step, retainer_plate.dxf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]
2025-09-10 ordered lgp, switch retainer plate
    [salt_booklamp-switch retainer plate.dxf, salt_booklamp.FCStd]
2025-09-26 exported mirror film outline, blackout film outline, and diffuser film outline for ordering
    [blackout film outline.dxf, diffuser outline.dxf, mirror film outline.dxf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]
2025-11-24 build7 fixes - interposer for pcb error, new switch retainer, new mirror film, adhesive film to test
    [Interposer-B_Cu.gbr, Interposer-B_Mask.gbr, Interposer-B_Paste.gbr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]
2026-02-03 Current status: need to assemble and test interposers then build some test units. Checking in any changes while this has been dormant.
    [salt_booklamp-switch retainer plateSketch045.dxf, salt_booklamp.FCStd]
2026-04-21 Current status: debugged and fixed 4 boards, need to finalize firmware and finish building these 4. All lamps from first build came unglued, need to revise design/assembly to fix this
    [Interposer.kicad_pcb, Interposer.kicad_sch, Interposer_new.kicad_pcb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]
